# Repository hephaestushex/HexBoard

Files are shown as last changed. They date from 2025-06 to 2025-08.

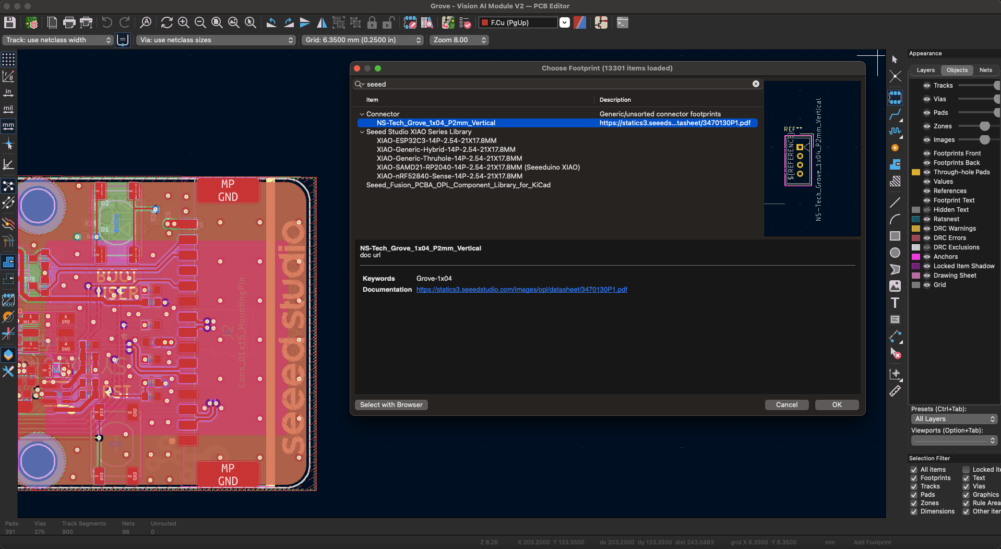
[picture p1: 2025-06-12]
pcb_right/OPL_Kicad_Library-master/images/19.png

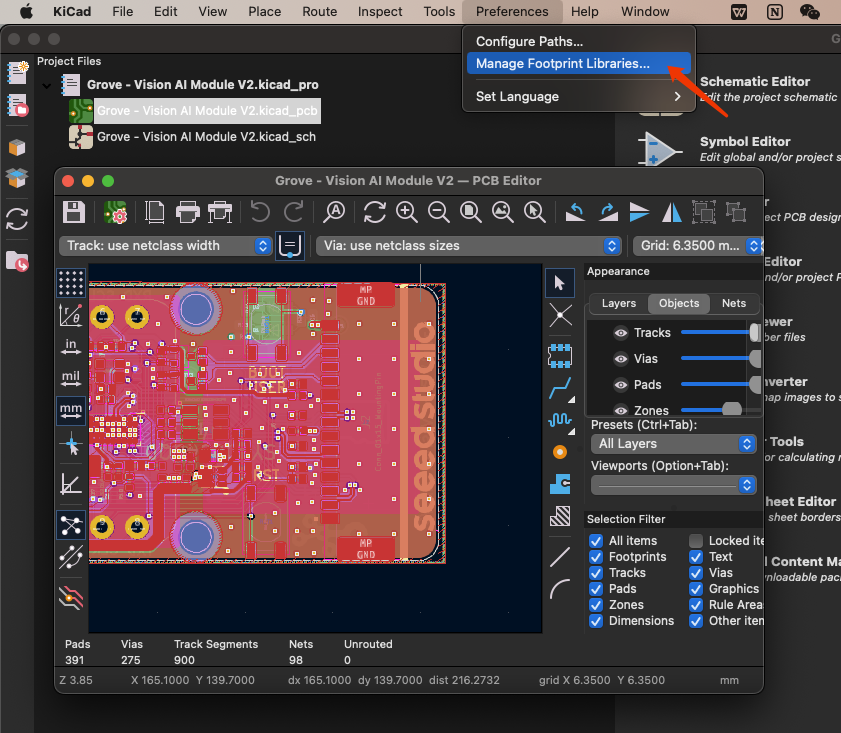
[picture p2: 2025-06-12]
pcb_right/OPL_Kicad_Library-master/images/4.png

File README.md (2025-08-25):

# HexBoard







A wireless split keyboard designed by HephaestusHex. It uses the SEEED Studio XIAO nRF52840 for wireless bluetooth connectivity

I made this split keyboard because it was a great project for learning PCB design, ergonomics, case design, keyboard firmware, and more. I wanted to make a split keyboard specifically because during my research, I found it's better than a regular keyboard because of ergonomics that I won't get into. Ben Vallack has [videos](https://www.youtube.com/@BenVallack) that gets into the details.

# YouTube Demo

Access the youtube demo [here](https://www.youtube.com/watch?v=F45BFvxeQR0)

# CAD
## PCB











## Case



# Firmware

This kb uses ZMK for firmware. Due to ZMK's requirement of using another repo, all of the zmk code is in this [repo](https://github.com/hephaestushex/zmk-config-hexboard)

# BOM

| Name | Reference | Quantity | Value | Footprint | Part Link | Description | Price (USD) |
| --- | --- | --- | --- | --- | --- | --- | --- |
| 1N4148 Diodes | D1-18 | 36 | 1N4148 | D_DO-35_SOD27_P7.62mm_Horizontal | [AliExpress](https://www.aliexpress.us/item/1005004962400215.html) | Used for switch matrix | $1.01 |
| Gateron KS-33 Low Profile Switches | SW1-18 | 36 |  | Gateron-KS33-Solderable-1U | [AliExpress](https://www.aliexpress.us/item/1005006637645158.html) | Low-profile switches | $25.22 |
| Seeed XIAO nRF52840 | U1 | 2 |  | XIAO-nRF52840-DIP-Batt | [AliExpress](https://www.aliexpress.us/item/1005008484816031.html) | Bluetooth MCU for wireless split connectivity | $31.09 |
| 601730 3.7V LiPo Battery | J1 | 2 | 250mAh | PinHeader_1x02_P2.54mm_Vertical | [AliExpress](https://www.aliexpress.us/item/1005006584143607.html) | Battery for MCU | $5.47 |
| PCB | hexboard-left, hexboard-right | 2 |  |  | [JLC PCB](https://jlcpcb.com/) | PCB for the left and right halves of the keyboard | $24.33 |
| M3x5x4 Heatset Inserts |  | 8 |  |  | [AliExpress](https://www.aliexpress.us/item/4000232858343.html) | Heatset inserts for mounting components | $6.23 |
| M3x6 Screws | H1-4 | 8 |  | MountingHole_3.2mm_M3 | [AliExpress](https://www.aliexpress.us/item/32794842281.html) | Screws for securing the PCB to the case | $2.89 |
| Slide SPDT Switches | SW19 | 2 |  | SW_Slide_SPDT_Straight_CK_OS102011MS2Q | [AliExpress](https://www.aliexpress.us/item/1005007162182882.html) | Slide switch for power control | $1.46 |
| Case |  |  |  |  |  | Free since I already have filament | $2.78 |
| Keycaps |  |  |  |  |  | Free since I already have filament | $0.66 |
| AliExpress Total  |  |  |  |  |  |  | $75.80 |
| JLCPCB Total  |  |  |  |  |  |  | $30.80 |
| Grand Total |  |  |  |  |  |  | $113.04 |

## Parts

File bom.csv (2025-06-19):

Name | Reference | Quantity | Value | Footprint | Part Link | Description | Price (USD)
1N4148 Diodes | D1, D2, D3, D4, D5, D6, D7, D8, D9, D10, D11, D12, D13, D14, D15, D16, D17, D18 | 36 | 1N4148 | D_DO-35_SOD27_P7.62mm_Horizontal | https://www.aliexpress.us/item/1005004962400215.html | Used for switch matrix | $1.01
Gateron KS-33 Low Profile Switches | SW1, SW2, SW3, SW4, SW5, SW6, SW7, SW8, SW9, SW10, SW11, SW12, SW13, SW14, SW15, SW16, SW17, SW18 | 36 |  | Gateron-KS33-Solderable-1U | https://www.aliexpress.us/item/1005006637645158.html | Low-profile switches | $25.22
Seeed XIAO nRF52840 | U1 | 2 |  | XIAO-nRF52840-DIP-Batt | https://www.aliexpress.us/item/1005008484816031.html | Bluetooth MCU for wireless split connectivity | $31.09
502030 3.7V LiPo Battery | J1 | 2 | 250mAh | PinHeader_1x02_P2.54mm_Vertical | https://www.aliexpress.us/item/1005006584143607.html | Battery for MCU | $5.47
PCB | hexboard-left, hexboard-right | 2 |  |  | https://jlcpcb.com/ | PCB for the left and right halves of the keyboard | $24.33
M3x5x4 Heatset Inserts |  | 8 |  |  | https://www.aliexpress.us/item/4000232858343.html | Heatset inserts for mounting components | $6.23
M3x6 Screws |  | 8 |  |  | https://www.aliexpress.us/item/32794842281.html | Screws for securing the PCB to the case | $2.89
Slide SPDT Switches | SW19 | 2 |  | SW_Slide_SPDT_Straight_CK_OS102011MS2Q | https://www.aliexpress.us/item/1005007162182882.html | Slide switch for power control | $1.46
Total |  |  |  |  |  |  | $97.7

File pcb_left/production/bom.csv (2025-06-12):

Designator | Footprint | Quantity | Value | LCSC Part #
D1, D10, D11, D12, D13, D14, D15, D16, D17, D18, D2, D3, D4, D5, D6, D7, D8, D9 | D_DO-35_SOD27_P7.62mm_Horizontal | 18 | 1N4148
J1 | PinHeader_1x02_P2.54mm_Vertical | 1 | Conn_01x02_Pin
SW1, SW10, SW11, SW12, SW13, SW14, SW15, SW16, SW17, SW18, SW2, SW3, SW4, SW5, SW6, SW7, SW8, SW9 | Gateron-KS33-Solderable-1U | 18 | SW_Push_45deg
SW19 | SW_Slide_SPDT_Straight_CK_OS102011MS2Q | 1 | SW_SPDT
U2 | XIAO-nRF52840-DIP-Batt | 1 | XIAO-nRF52840-SMD

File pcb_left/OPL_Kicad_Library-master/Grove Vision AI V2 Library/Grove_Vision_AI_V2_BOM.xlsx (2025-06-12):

Layer Jump | Number | Name | Specification | Operating Temperature | MPN Code | Quantity | Base | Plug Position | Process
N | 301010000 | SMD RES 0R-5%-1/16W;0402 |  | -55°C to 155°C | RC0402JR-070RL | 3 | 1 | R29,R30,R39 | SMT1
N | 301010004 | SMD RES 10K-5%-1/16W;0402 |  | -55°C to 155°C | RC0402JR-0710KL | 7 | 1 | R5,R7,R8,R23,R24,R31,R38 | SMT1
N | 301010008 | SMD RES 510K-5%-1/16W;0402 |  | -55°C to 155°C | RC0402JR-07510KL | 1 | 1 | R35 | SMT1
N | 301010456 | SMD RES 100K-1%-1/16W;0402 |  | -55°C to 155°C | RC0402FR-07100KL | 7 | 1 | R6,R10,R11,R16,R32,R33,R37 | SMT1
N | 301010495 | SMD RES;5.1K-1%-1/16W;0402 |  | -55°C to 155°C | RC0402FR-075K1L | 3 | 1 | R2,R3,R36 | SMT1
N | 301010746 | SMD RES 2.2K-1%-1/16W;0402 |  | -55°C to 155°C | RC0402FR-072K2L | 10 | 1 | R1,R4,R13,R14,R15,R19,R20,R21,R22,R40 | SMT1
N | 301011331 | SMD RES 22.1K-1%-1/16W;0402 |  | -55°C to 155°C | RC0402FR-0722K1L | 2 | 1 | R26,R34 | SMT1
N | 302010004 | SMD CAP Ceramic 100nF-16V-10%-X7R;0402 |  | -55°C to 125°C | CC0402KRX7R7BB104 | 18 | 1 | C5,C8,C13,C20,C21,C22,C23,C24,C25,C26,C27,C29,C30,C31,C32,C35,C36,C39 | SMT1
N | 302010006 | SMD CAP Ceramic 10nF-50V-10%-X7R;0402 |  | -55°C to 125°C | CC0402KRX7R9BB103 | 1 | 1 | C3 | SMT1
N | 302010049 | SMD CAP Ceramic 12pF-50V-5%-NPO;0402 |  | -55°C to 125°C | CC0402JRNPO9BN120 | 2 | 1 | C14,C15 | SMT1
N | 302010051 | SMD CAP Ceramic 220nF-16V-10%-X7R;0402 |  | -55°C to 125°C | CC0402KRX7R7BB224 | 1 | 1 | C16 | SMT1
N | 302010407 | SMD CAP Ceramic 4.7uF-10V-10%-X5R;0402 |  | -55°C to 85°C | CC0402KRX5R6BB475 | 7 | 1 | C4,C6,C7,C9,C10,C28,C34 | SMT1
N | 302010519 | SMD CAP Ceramic 10uF-10V-20%-X5R;0402 |  | -55°C to 85°C | CC0402MRX5R6BB106 | 2 | 1 | C11,C37 | SMT1
N | 302013249 | SMD CAP Ceramic 1uF-10V-10%-X5R;0402 |  | -55°C to 85°C | CL05A105KP5NNNC | 5 | 1 | C1,C2,C17,C18,C19 | SMT1
N | 303010544 | SMD Inductor 4.7uH-20%-1.1A;0806 |  | -40°C to 105°C | VLS201610HBX-4R7M-1 | 1 | 1 | L1 | SMT1
N | 303011858 | SMD Inductor 470nH-20%-2.6A;0603 |  | -40°C to 125°C | TFM160808ALC-R47MTAA | 2 | 1 | L2,L3 | SMT1
N | 304011053 | SMD Diode Schottky 40V-1A;SOD-323 |  |  | B5819WS SL | 4 | 1 | D1,D2,D3,D4 | SMT1
N | 304090121 | SMD LED Clear-Green;0402 | As posted |  | BL-HGE37A-AV-TRB | 1 | 1 | LED2 | SMT1
N | 304090746 | SMD LED Clear-Yellow;0402 | As posted |  | 16-213/Y2C-AN2Q1B/3T | 1 | 1 | LED1 | SMT1
N | 305030071 | SMD MOSFET N-CH 20V-500mA;SOT-523 |  |  | CJ1012 | 5 | 1 | Q1,Q2,Q3,Q4,Q5 | SMT1
N | 306011444 | SMD Crystal;24MHz-12pF-10ppm-4P-2.0*1.6*0.5mm |  | -40°C to 85°C | Y2400FE001 | 1 | 1 | X1 | SMT1
N | 310011697 | SMD IC MCU;Dual Cortex-M55 Core(Max 400MHz)-With a 400MHz NPU;WLCSP-65 | L5.58*W2.27mm | -40°C to 85°C | HX6538-A01TWA | 1 | 1 | U1 | SMT1
N | 310032794 | SMD IC PMIC;DCDC Buck-ADJ-2.2MHz-4A;DFN1.5×1.5-6 |  | -40°C to 85°C | SY80004DQD | 2 | 1 | U4,U6 | SMT1
N | 310032813 | SMD IC PMIC;LDO-1.8V-300mA;XTDFN-1*1-4L |  | -40°C to 125°C | SGM2036S-1.8XXDH4G/TR | 1 | 1 | U3 | SMT1
N | 310071431 | SMD IC Interface USB to High Speed TTL;QFN16 | USB to High-Speed Serial Port | -40°C to 85°C | CH343P | 1 | 1 | U2 | SMT1
N | 310091468 | SMD IC Memory;128Mbit-1.8V;SOIC-8 |  | -40°C to 85°C | W25Q128JWSIQ | 1 | 1 | U5 | SMT1
N | 311020009 | SMD Top Button 4N;4P-L4.6*W3.2*H2.5mm |  | -20°C to 70°C | SKRPADE010 | 1 | 1 | RST1 | SMT1
N | 311020518 | SMD Top Button 1.57N;4P-L4.6*W3.2*H2.5mm |  | -30°C to 85°C | SKRPABE010 | 1 | 1 | BOOT1 | SMT1
N | 312030502 | SMD DIGITAL MIC OMNI -26dBFS;OCLGA-4:3.5*2.65*0.94mm |  | -40˚C to 100˚C | MSM261D3526H1CPM | 1 | 1 | MIC1 | SMT1
N | 319015667 | PCB;Grove - Vision AI Module V2 -蓝油白字-4层 | 20*40*1.6mm-ENIG-FR4;Steel mesh code；404012305 |  |  | 1 | 1 |  | SMT1
N | 320011358 | SMD USB TYPE C-W/P;12+4P-8.94*7.35*3.26mm |  | -30°C to 85°C | USB-31C-F-16P-L7.35 | 1 | 1 | J1 | SMT1
N | 320031231 | DIP Black Female Header VERT;1*7P-2.54-5.0mm |  | -40℃ to 105℃ |  | 2 | 1 | P8,P9 | Unit
N | 320060904 | SMD FPC CONN Bottom Contact;15P-1.0mm;L19.9*W6.76*H2.0mm |  | -30°C to 85°C | ST-FPC-W102015-D | 1 | 1 | J2 | SMT1
N | 320090535 | SMD uSD Card Holder;9+4P-L11.25*W6.96*H1.42mm |  | -25°C to 70°C | ST-TF-MR267 | 1 | 1 | J5 | SMT1
N | 320110032 | SMD Grove Female Header-Beige;4P-2.0-90D | 2.0-4PHorizontal Mount with Locking Socket |  | PHS-4A horizontal mount | 1 | 1 | J3 | SMT1

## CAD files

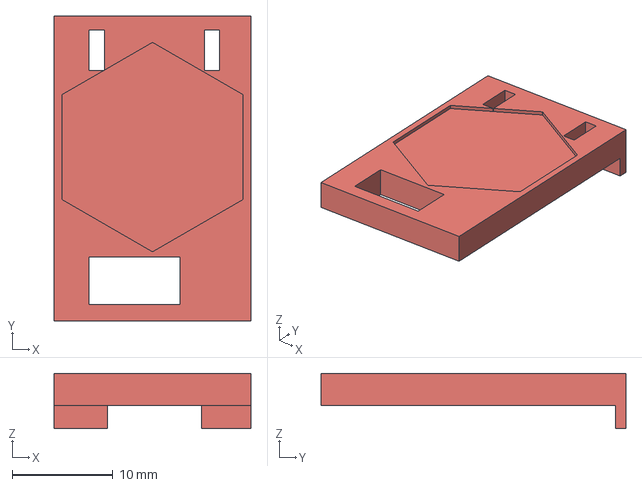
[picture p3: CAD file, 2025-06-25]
cad/Right Cover.step
19.5 x 30.3 x 5.50 mm

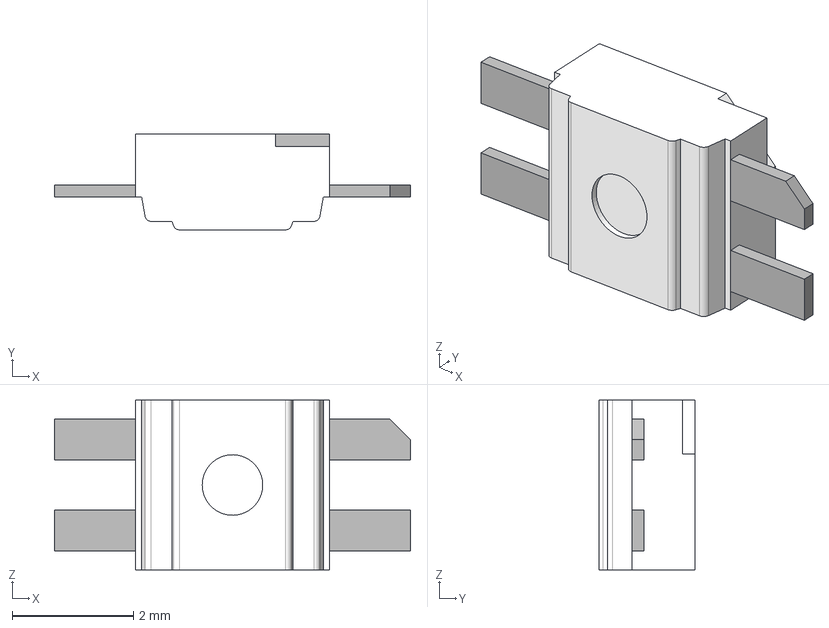
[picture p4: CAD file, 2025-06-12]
pcb_left/cheyao macropad main PCB-third_party_neopixel.petty/SK6812MINI-E.step
5.88 x 1.58 x 2.80 mm

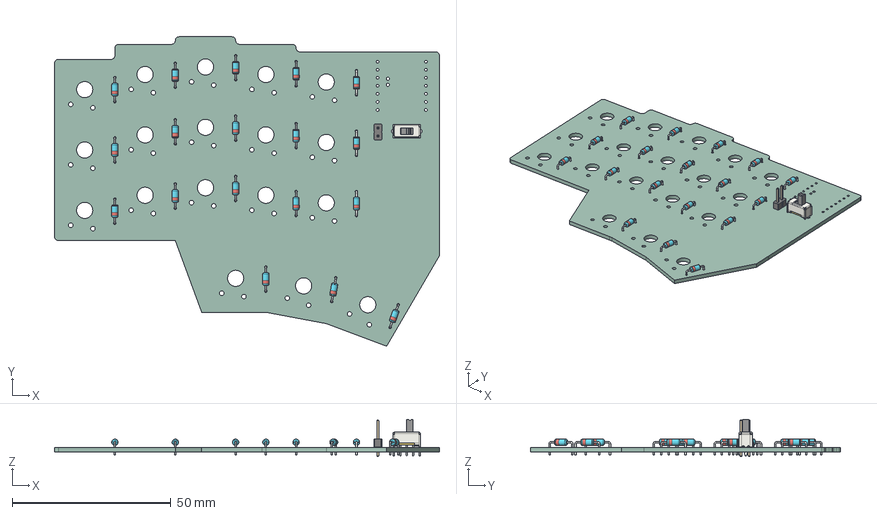
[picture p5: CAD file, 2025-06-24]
pcb_left/hexboard_left.step
121.4 x 97.6 x 11.7 mm
D_DO-35_SOD27_P7.62mm_Horizontal x 18
PinHeader_1x02_P2.54mm_Vertical
SW_Slide_SPDT_Straight_CK_OS102011MS2Q
hexboard_PCB

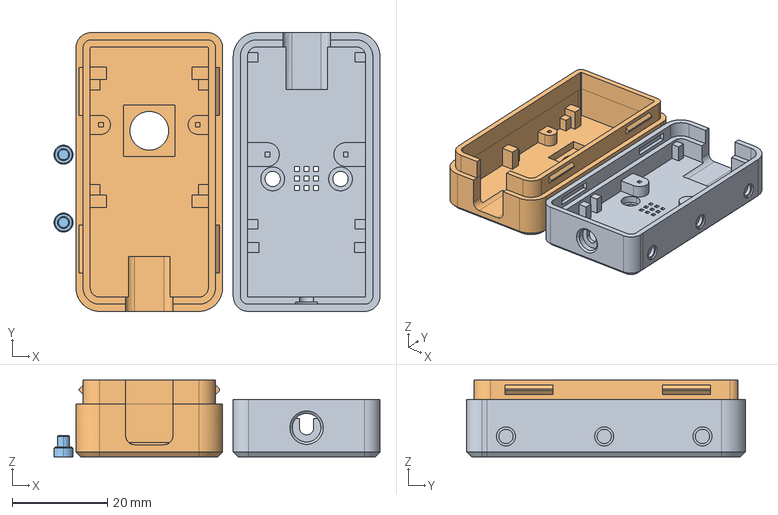
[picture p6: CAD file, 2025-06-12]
pcb_left/OPL_Kicad_Library-master/Grove Vision AI V2 Library/himax.stp
68.4 x 58.5 x 16.1 mm

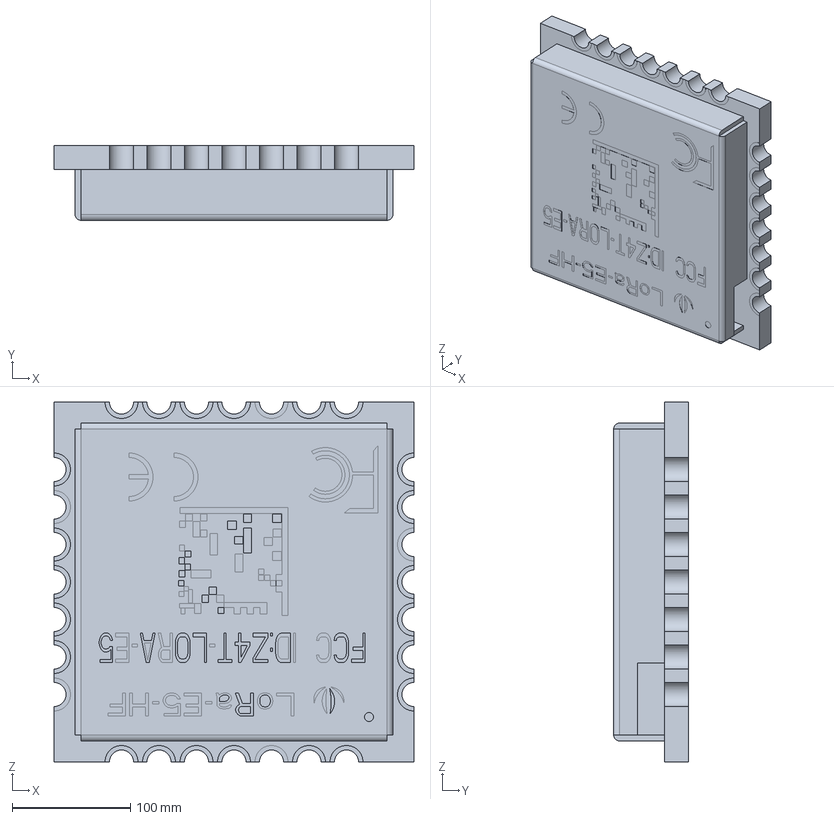
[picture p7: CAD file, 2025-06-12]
pcb_left/OPL_Kicad_Library-master/Seeed Studio Wio Series/Wio-E5-LE/LoRa-E5-LE-HF_3D_File.stp
304.8 x 63.8 x 304.8 mm

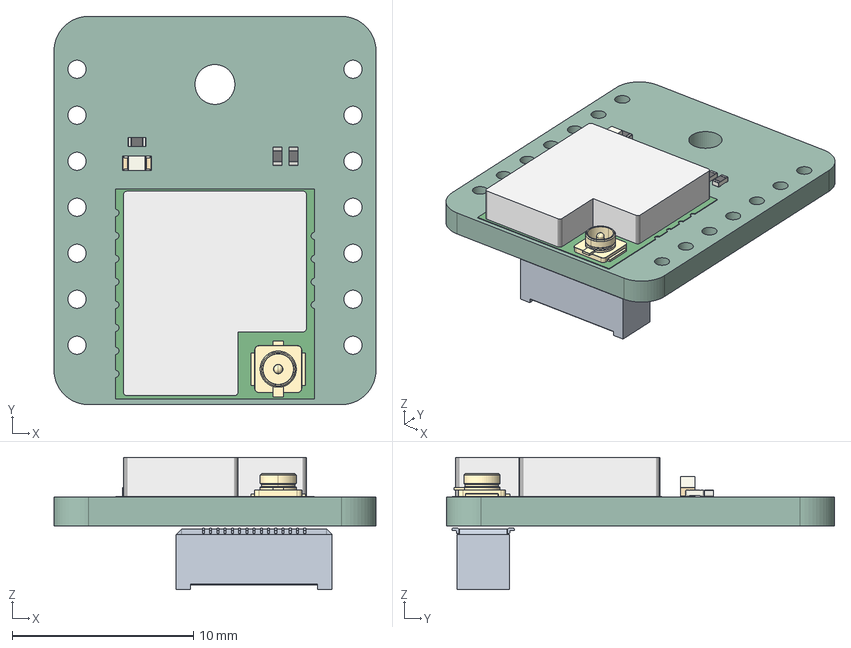
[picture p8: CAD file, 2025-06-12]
pcb_left/OPL_Kicad_Library-master/Seeed Studio Wio Series/Wio-SX1262/Wio-SX1262_for_XIAO_3D_file.step
17.8 x 21.4 x 7.30 mm
R_0402_1005Metric x 3
LED_0603_1608Metric
PCB
BF04-30pin-35H
Wio-SX1262 for XIAO V1.0_PCB

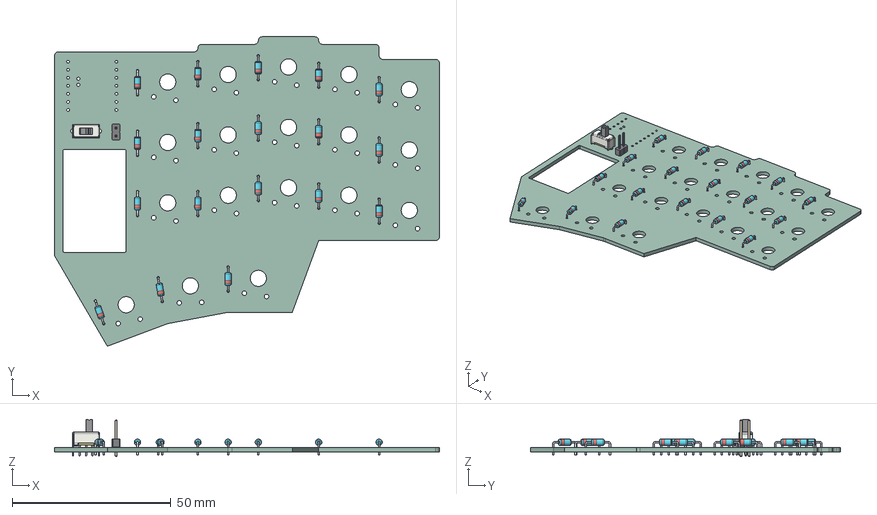
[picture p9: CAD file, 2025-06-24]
pcb_right/hexboard_right.step
121.4 x 97.6 x 11.7 mm
D_DO-35_SOD27_P7.62mm_Horizontal x 18
PinHeader_1x02_P2.54mm_Vertical
SW_Slide_SPDT_Straight_CK_OS102011MS2Q
hexboard_PCB

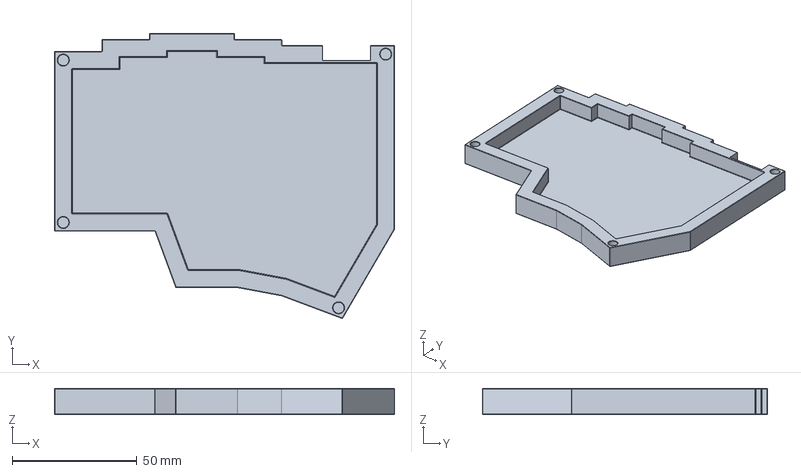
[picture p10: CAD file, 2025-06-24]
production/case/Left Shell.step
136.5 x 114.4 x 10.5 mm

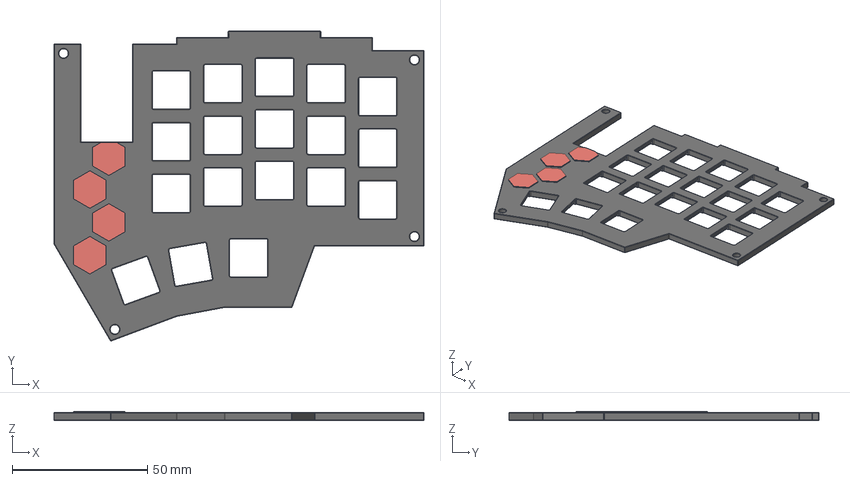
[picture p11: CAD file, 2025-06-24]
production/case/Right Plate.step
136.5 x 114.4 x 3.40 mm

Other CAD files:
cad/Left Cover.step
production/case/Right Shell.step
cad/Left Plate.3mf
cad/Left Plate.step
cad/Right Plate.3mf
cad/Right Shell.step
pcb_left/OPL_Kicad_Library-master/Grove Vision AI V2 Library/himax.3mf
pcb_right/OPL_Kicad_Library-master/Grove Vision AI V2 Library/himax.3mf
production/case/Left Plate.3mf
production/case/Left Plate.step
production/case/Right Plate.3mf

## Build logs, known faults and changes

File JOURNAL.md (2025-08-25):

---
title: "HexBoard"
author: "hephaestushex"
description: "A wireless split keyboard powered by the nRF52840"
created_at: "2025-06-05"
---

# Total Time Spent: 33.5 Hours (including building)

# June 9th: Got some initial planning done

## Keyboard Layout

I started off by creating a keyboard layout.
Some tinkering later, this is what it looks like in Keyboard Layout Editor



It's only one half, with no column stagger (I haven't measured my hands yet) but it would come out to a 36-key layout



As for the keymap, I liked this one by Rico Sta. Cruz. I'll probably use QWERTY, but I like the way they navigate between layers

## Microcontroller

I initially wanted to make this keyboard wireless, considering the state of my desk

WIN_20250609_16_52_57_Pro
my desk rn... not looking good

Unfortunately, after a post on slack and some research, this isn't feasible. I could use an aliexpress clone, but apparently it's not reliable

Anyway, by this point I decided that a pi pico would be better. Ideally, usb-c, as the microUSB connectors tend to break off.

I started by looking at the Seeed Studio XIAO RP2040 board. With the split connectivity (TX/RX) pins, there is 9 more pins, which would work out for my layout.

It's tight, but it might just work.

But hold on... I found a Seeed Studio XIAO nRF52840 Board, and it is similar to the nice!nano, but so much more cheaper. The only caveat is that the battery pins are exposed by pads. A google search yielded the ergonaut one, which solves this problem by using holes and filling them with solder.


location of the battery pins


solution used in the ergonaut one

## Keyswitches

I want this keyboard to be low-profile, so I went looking for some low profile keyswitches. I ended up finding the gateron ks-33 low profile switches, which looks good.

## Miscellaneous Parts

I'll use THT diodes for the matrix, probably 1N4148 diodes.

**Total time spent: 3h**

# June 10th: PCB Design

With all the hardware choices out of the way, I started designing the schematic and PCB.

I downloaded some libraries and setup the key switch matrix



my switch matrix.

I plan on making this a reversible matrix, so its only one half.

I then decided to do per key RGB, so I setup that too.



Its much simpler.

From there I wired up the microcontoller and battery



With that out of the way, I started on the PCB, which was relatively easy.



This is the location I settled on.

**Total time spent: 3h**

# June 11th: PCB Routing

I used @cheyao's reversible sk6812 mini LED footprint, and positioned those and the leds.

I then wired all of them up.



I don't like the wiring towards the MCU, so I'll probably fix it tomorrow.

I couldn't decide on the mcu footprint, so I'm still working on it.
For now I'm using this footprint used in the ergonaut one


Also it appears that a reversible footprint does not exist for the ks-33 so looks like I'm making two halves.

After all of that, this is the final pcb for today.



**Total time spent: 1.5h**

# June 12th: Rerouting + New PCB Footprint

I started off by realizing I probably can't SMD solder, so I created this footprint, using the XIAO nRF52840 DIP as a base and added the pads from the ergonaut one footprint.



The holes are so that I can use the soldering method used in the ergonaut one.

From, there I positioned the switch and battery connector.



The battery connector is simply two holes for two wires.

I then placed some mounting holes, two in the left half and one on the right half,
and finally one in the thumb cluster



Finally, the board outline and its time to reroute, this time beautifully.

I had to shuffle around some parts, replace a few footprints. I also decided to nix the leds, because a, I have no idea how to smd solder, and b, soldering 144 smd pins is too much.

This is the result







I exported that, then flipped it over and rerouted





the cost comes out to $8.50 per pcb.

To check if I'm still under the limit, I decided to put together the BOM.



I sourced everything from aliexpress except the pcb and case (not on yet since I have no idea how much filament it needs)

I also made the BOM in table format in the README.md

**Total time spent: 4h**

# June 13th: Case Design and PCB Redesign

I started to design the case, when I realized that my ergonomic setup wouldn't work with Keyboard Layout editor, as apparently it can't handle eighth units.
So I'm stuck designing my own plate. 

When I hopped into kicad, I realized that my thumb cluster was not properly designed, so I basically redid the pcb, this time capturing the measurements necessary. This also helped me reduce the number of vias I used, making it cheaper!

## Right Half



## Left Half



I also redid the cost calculations with the new pcbs, but it didnt change.

Now, I can start with the case/plate.

Since Keyboard layout editor doesn't support eight units, I have to design my own plate, which kinda sucks.

Anyway, I tried my best to create my own plate, and this is what I go before I gave up.



This was my first time using fusion, so it took forever, dealing with constraints, rectangular patterns and so much more.

**Total time spent: 5h**

# June 15th: Case Redesign

This clearly wasn't working, so I tried KLE again. I just ignored the warnings, and came up with this plate.



its so much better, and I can properly deal with this. Obviously the plate isn't meant to be a square, so thats a tomorrow problem

**Total time spent: 30min**

# June 16th: Case Design (for real this time)

I decided to start designing the case, and it looked good!

45 mins in and this is what I have



It looks good, so I designed a cross section to see how it would mount



its way too large (2 cm), so I realized i should probably use m2 bolts instead.

Back to PCB design ... sigh

It wasn't too bad, I just made two different folders for each half. 

Here's the new folder structure



A quick edit in the footprint assignment tool yielded a fixed pcb.

.

**Total Time spent: 1h**

# June 17th: Case Done*

I started off with some research as to the dimensions of my case. It was very boring, but eventually 
I found out that the distance between the bottom of the plate and the top of the case floor should be 4.5mm

The research led me to find out that my current hardware is good, so I just went with the m3 bolts. The heads will protrude now, but that should be fine.

The fact that the heads will protrude made me have to move the bolts to the side, which ended up looking like a sandwich mount, like this, except for the fact that the bolts will come from the top instead



Heres what the bottom looks like, after redoing the pcbs, schematics, and the sketch



As for the top, it was as simple as copying over the outline and fixing the holes in place.



The plate should be 3mm thick, with 1.2mm thick rectangles for the switch to clip onto. I didn't design these yet, as I want to do it after receiving the switches, which would allow me to experiment with mounting styles.

heres how the plate looks after a quick extrusion





i still need to fillet it tho

**Total time spent: 3h**

# June 18th: Case Fully Done

I started off by redoing the extrusions, so I can create a divot.

It was time consuming, but 30 mins later I got this 



You can see the parts where the switch clips to.

I also took some time to fillet the entire case.

Filleted the top plate:



And the bottom case:



That's pretty much it for the case so I exported, both left and right.

I put the cad files in the repo, and that's all I did for today.



**Total time spent: 1h**

# Jun 19th: Firmware Done*

Since I'm using the nRF52840, my only options for firmware are ZMK and KMK. The docs for KMK say that it has to be precompiled, and a whole bunch of nonsense that made it not worth it to use KMK. ZMK isn't any easier, but at least there's a lot of documentation for it.

I started off with Joe Scotto's tutorial, but it looked out of date, plus mine is split. So, time to delve into the docs.

It took a while to find what I needed, since the actual development of shields was put in the later sections of the docs. I pretty much installed zmk, created a new repo for it, and started creating!

## Some screenshots of the code required









The last image is of my keymap. For now, its pretty sparse, but I plan on filling it out fully.

an hour in, its time for building!

I sure hope that no bugs will come!

**There. were. so. many. bugs.**

The terrible part is that it takes forever for these bugs to show up, since it takes time to build.



The first two were the initial builds, but the last three are bugs in my code.

If you noticed in my keymap, I actually used a Colemak layout. I wanted to learn colemak, so I'm taking this as an opportunity to learn it.

so while it takes time to build ...



im learning colemak!



Finally at 1:23 it built.



FINALLY!!!!

Here's my colemak accuracy by the way:



That's pretty much everything I think I have to do before I submit.

I pushed the two uf2 files to github



I took some time to revise the README and the BOM.

AliExpress for some reason changed the prices on me, so I have to update the prices. It also allowed me to fix items that ship later.

That looked to be pretty much everything, so I checked the website to see if I'm missing anything.

I was missing a couple of images, plus some BOM formatting. It took a while to place all the switches, so in total, about 45 mins.



This is how it looked once I placed all of them. 

That's it, so I'm going to submit this.

**Total time spent: 3.5h**

# June 23rd: Case Redesign

I already submitted this in the slack, but I realized my case didn't have much design to it. I wanted to create a design to boost my chances of getting accepted, plus, i didn't like the look of a plain pcb.

1h 30mins in, I got this:



I took some time to design around the xiao, but I liked this look in the end.

I meant to also add some color, so I re did the appearances close to what it would look like IRL



After doing that, I realized I didnt like the look of the xiao board, so I added some material to hide that aswell.

It allowed me to completely hide the usb-c port 



And this is the final design!



I have black and red pla filament, and this is what itll probably look like.

I also decided to take a render, and I added this to the README



From there I refactored the object and exported everything. I also took the time to colorize the case in the Bambu Slicer, and saved it as a 3mf file.



the colorized part is above all the black parts, so there is only one filament change.

Now, the assembly steps looks like solder diodes, switches, mcu, battery onto pcb, insert switches into plate, solder switches to PCB, screw plate to bottom shell. 

**Total time spent: 3h**

# July 10th: Assembly (Part One):

Note: I forgot to journal this, so this is written on july 23rd, when I finally got the batteries.

I received all the parts except for the battery, so I printed off the plate to start assembly.



as you can see, the plate and pcb are touching, meaning I cant use diodes

Unfortunately, the plate ended up being too thick, and the diodes wont fit. (it would have worked if it was SMD).

So I had to reprint thinner plates. After they printed I started snapping in the switches.




As you can see in the back, I also placed the diodes in the holes.

After this, I realized I had made another mistake. This time I foolishly assumed in my cad that I would SMD solder the XIAO. I had soldered on the headers, so now I had to remove them.



The process was pretty simple, with using diagonal cutters to cut the black parts, remove them, and then use the soldering iron plus some tweezers to remove each pin.

I then soldered the diodes + the mcu, cut the legs off, and soldered the switches as well.




Here's how it looked.

It was undercity tomorrow, so I basically speedran everything. I had forgotten to print the bottom part, so I put it to print and fell asleep. 

**Total time spent: 4h**

# July 11th: Assembly (Part Two)

I woke up (at like 4AM), put the heatset inserts in, and finally assembeled the keyboard.




I slapped the basic firmware in, and left for undercity. In Github HQ I realized that certain keys didn't work, so I had to fix it later.

**Total time spent: 30mins**

# July 22nd: Assembly (Part Three):

I received the batteries (finally!), and realized the keyboard still doesn't work. What I did was find the keys that didn't work, replaced them with a letter (T) and tried again. Looks like middle key on the thumb cluster on the left half doesn't work, and the entire thumb cluster on the right half doesn't work. I also figured out that bridging the pins on the left half worked, but not on the right. Looks like I fried a pin. I'll have to fix that. I had to leave, so that's all I did.

**Total time spent: 30mins**

# July 25th: Done! (sorta):

I wrote the title with the Hexboard, but since my current WPM is so slow, I switched back to my regular keyboard.

Part one: Battery

I tried getting the battery working, but for some reason I never got it working on the left half. I updated the firmware, resoldered the joints, but it still doesnt work. It works on the right half though. 
I added some code to the .overlay file in the zmk, and it supposedly reports the battery level. currently this doesn't matter, as zmk only reports the left half's battery, and only the right half is wireless. (the left half is only connected for power. Overall, this isn't too bad, as its only one usb-c wire on my desk. 

Part two: missed keys.

The only key on the left half that didn't work was the modifier, but upon further inspection it appeared that I forgot to solder a diode. As for the right half, it was more complicated. I rebuilt the firmware, using another pin, and soldered a wire from that pin (pin 7) to that row. I still had one problem though. The reset button on the right half was broken, and I had to find a workaround. I ended up grabbing some tin foil and touching that to the contacts. Only one key worked, so I inspected the board even more. It appeared that I burned the contacts on the PCB, so the traces never connected to the switch. I ended up soldering a wire to replace the traces that the switch couldnt connect to. 

WIN_20250726_16_46_26_Pro

WIN_20250726_16_46_30_Pro

WIN_20250726_16_47_52_Pro

With that, I was finished. I just had two more things that I wanted to fix/add. One was fixing the battery on the left half, but that means I would have to desolder the entire mcu and try to clean the joints up. There was also a chance that the battery board was simply fried, and I don't want to go through all that. The second one was adding ZMK studio support to my keyboard. This means that I can easily modify the keymap, without building new firmware.

It turns out that this process takes a while, as I have to define a physical layout. In the end, i got it in a web tool



and the ide



So I pushed it to Github and let it build, while I got some more tin foil.

After I reflashed the mcus, it worked!



So that's it! It's finished! 

I'll record some footage and upload it to youtube for a demo.

**Total time spent: 3h**

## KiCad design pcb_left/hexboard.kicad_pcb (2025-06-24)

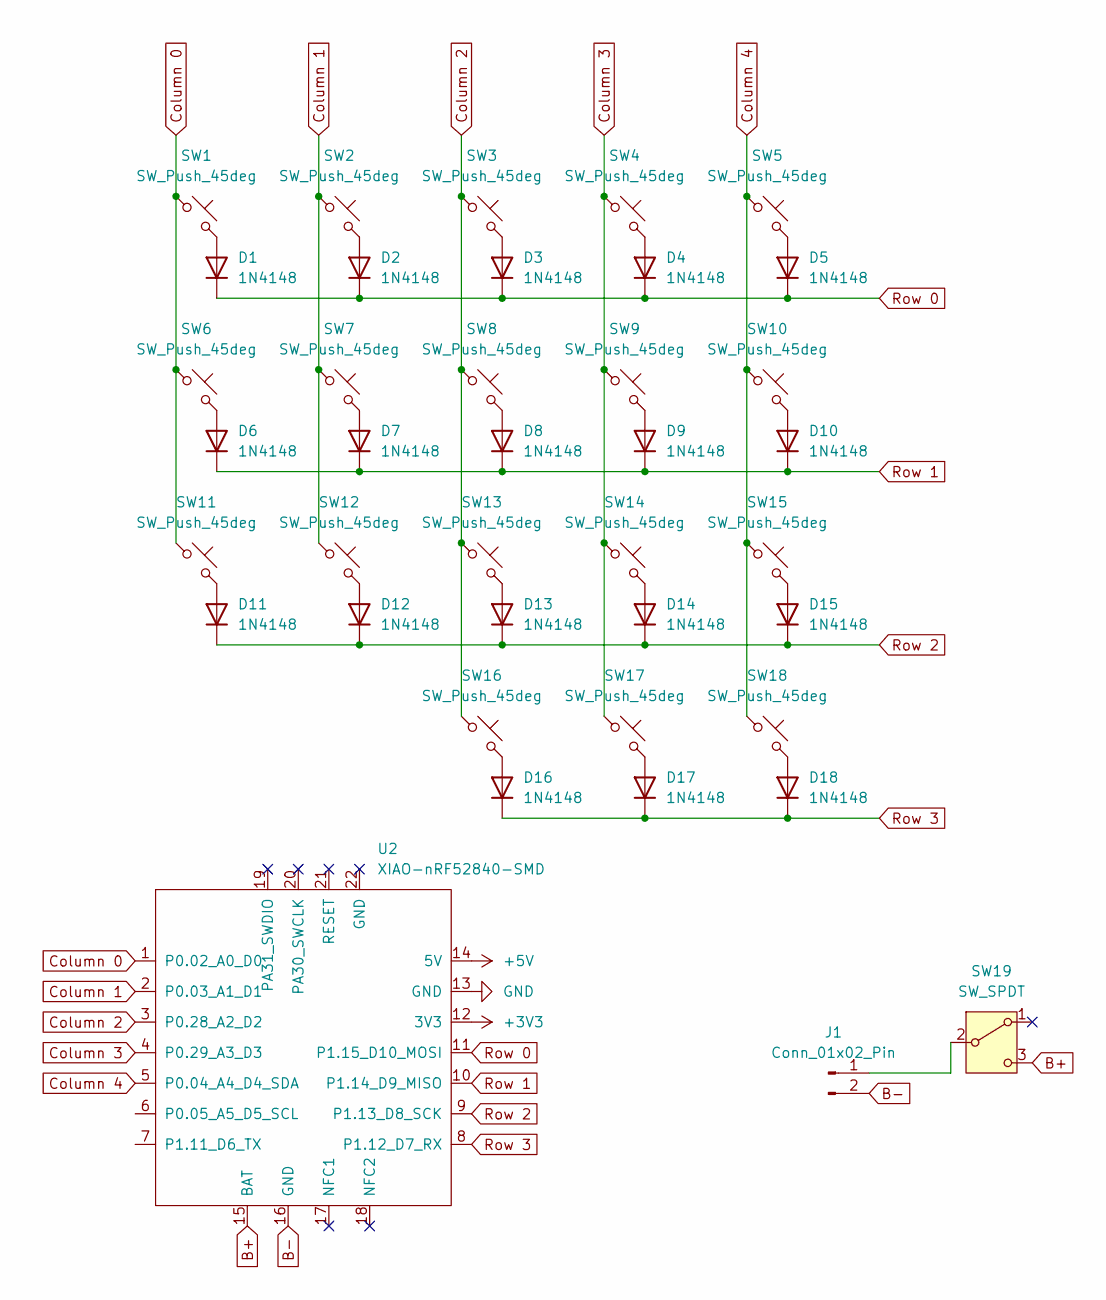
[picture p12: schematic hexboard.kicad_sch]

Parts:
D1, D2, D3, D4, D5, D6, D7, D8, D9, D10, D11, D12, D13, D14, D15, D16, D17, D18: 1N4148; D_DO-35_SOD27_P7.62mm_Horizontal
J1: Conn_01x02_Pin; PinHeader_1x02_P2.54mm_Vertical
SW1, SW2, SW3, SW4, SW5, SW6, SW7, SW8, SW9, SW10, SW11, SW12, SW13, SW14, SW15, SW16, SW17, SW18: SW_Push_45deg; Gateron-KS33-Solderable-1U
SW19: SW_SPDT; SW_Slide_SPDT_Straight_CK_OS102011MS2Q
U2: XIAO-nRF52840-SMD; XIAO-nRF52840-DIP-Batt

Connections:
+3V3: U2.12 (3V3)
+5V: U2.14 (5V)
B+: SW19.3 (C), U2.15 (BAT)
B-: J1.2, U2.16 (GND)
Column 0: SW1.1, SW6.1, SW11.1, U2.1 (P0.02_A0_D0)
Column 1: SW2.1, SW7.1, SW12.1, U2.2 (P0.03_A1_D1)
Column 2: SW3.1, SW8.1, SW13.1, SW16.1, U2.3 (P0.28_A2_D2)
Column 3: SW4.1, SW9.1, SW14.1, SW17.1, U2.4 (P0.29_A3_D3)
Column 4: SW5.1, SW10.1, SW15.1, SW18.1, U2.5 (P0.04_A4_D4_SDA)
GND: U2.13 (GND)
unnamed: D1.2 (A), SW1.2
unnamed: D2.2 (A), SW2.2
unnamed: D3.2 (A), SW3.2
unnamed: D4.2 (A), SW4.2
unnamed: D5.2 (A), SW5.2
unnamed: D6.2 (A), SW6.2
unnamed: D7.2 (A), SW7.2
unnamed: D8.2 (A), SW8.2
unnamed: D9.2 (A), SW9.2
unnamed: D10.2 (A), SW10.2
unnamed: D11.2 (A), SW11.2
unnamed: D12.2 (A), SW12.2
unnamed: D13.2 (A), SW13.2
unnamed: D14.2 (A), SW14.2
unnamed: D15.2 (A), SW15.2
unnamed: D16.2 (A), SW16.2
unnamed: D17.2 (A), SW17.2
unnamed: D18.2 (A), SW18.2
unnamed: J1.1, SW19.2 (B)
Row 0: D1.1 (K), D2.1 (K), D3.1 (K), D4.1 (K), D5.1 (K), U2.11 (P1.15_D10_MOSI)
Row 1: D6.1 (K), D7.1 (K), D8.1 (K), D9.1 (K), D10.1 (K), U2.10 (P1.14_D9_MISO)
Row 2: D11.1 (K), D12.1 (K), D13.1 (K), D14.1 (K), D15.1 (K), U2.9 (P1.13_D8_SCK)
Row 3: D16.1 (K), D17.1 (K), D18.1 (K), U2.8 (P1.12_D7_RX)

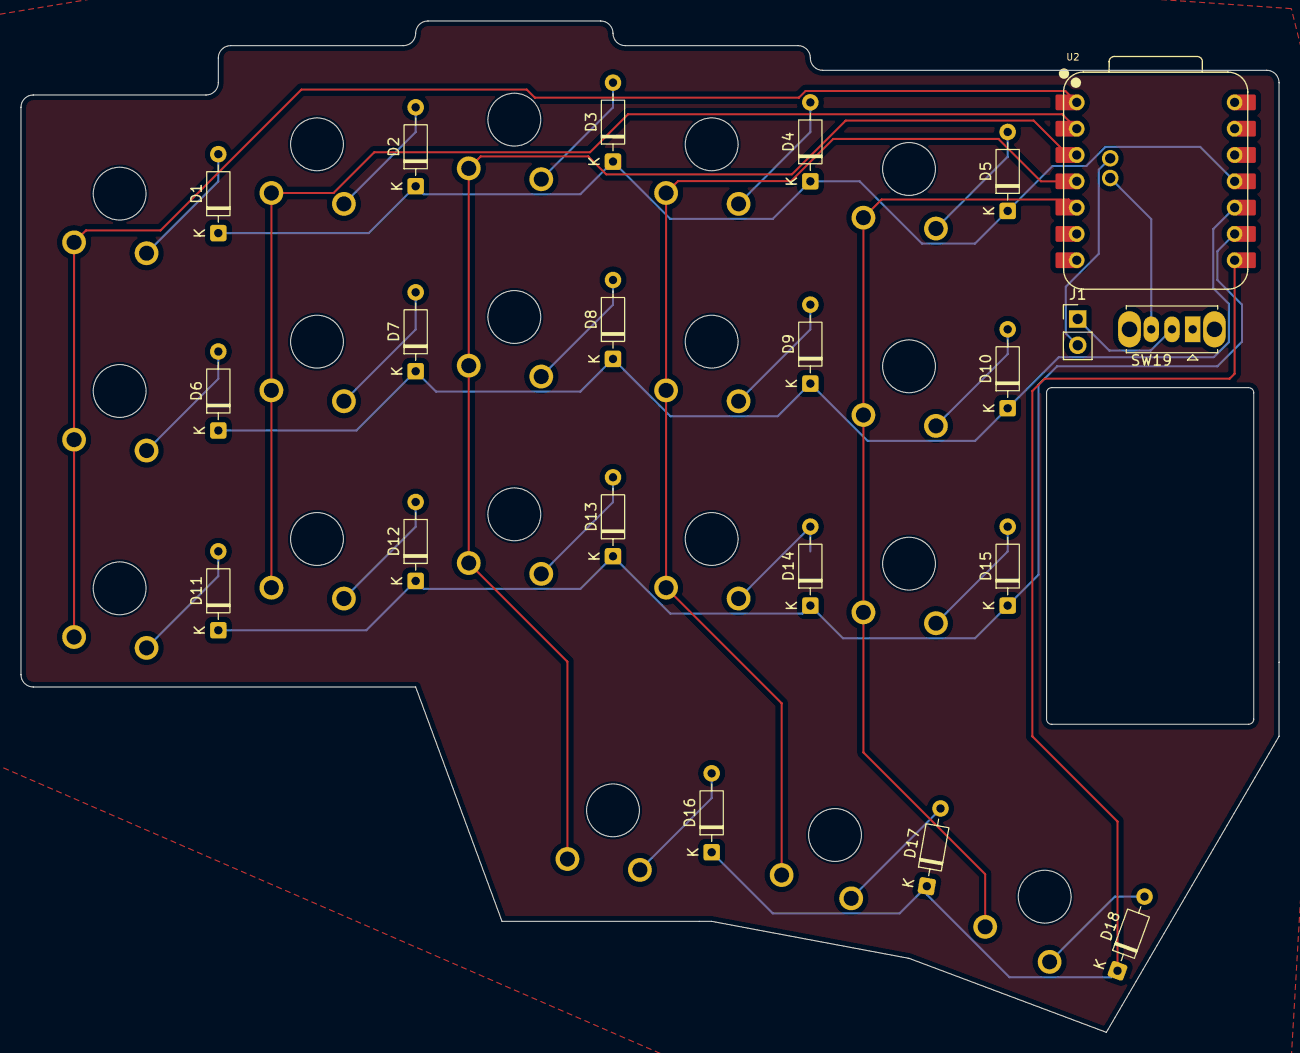
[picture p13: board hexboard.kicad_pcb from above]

Board: 2 copper layers, 121.4 x 97.6 mm, 39 parts (0 on the bottom side), 30 nets.

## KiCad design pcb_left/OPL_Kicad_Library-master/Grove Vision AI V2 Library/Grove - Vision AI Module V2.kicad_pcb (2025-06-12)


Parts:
BOOT1: SW_Push; SW_Push_1P1T_NO_Vertical_Wuerth_434133025816
C1, C2, C17, C18, C19: 1uF; C0402
C3: 10nF; C0402
C4, C6, C7, C9, C10, C28, C34: 4.7uF; C0402
C5, C8, C13, C20, C21, C22, C23, C24, C25, C26, C27, C29, C30, C31, C32, C35, C36, C39: 100nF; C0402
C11, C37: 10uF; C0402
C14, C15: 12pF; C0402
C16: 220nF; C0402
D1, D2, D3, D4: B5819WS; D0805_SOD323
D5, D6, D7, D8: DNP; R0402; MPN DF2S6.8FS
J1: USB_C_Receptacle_USB2.0; USB2.0-TYPE-C
J2: Conn_01x15_MountingPin; FPC_DNC_15P_1.0mm
J3: Conn_01x04_MountingPin; 4P-SMD-2.0mm-RIGHT
J5: ST-TF-MR267; SD-TF-MR267; MPN SD-TF-MR267
L1: VLS201610HBX-4R7M-1; L0806
L2, L3: 470nH; L0603
LED1: Yellow; LED0402
LED2: Green; LED0402
M1: XIAO Connector/DNP; XIAO_Socket
MIC1: MSM261D3526H1CPM; MIC6P-3.5X2.65X0.94MM
Q1, Q2, Q3, Q4, Q5: CJ1012; SOT523
R1, R4, R13, R14, R15, R19, R20, R21, R22, R40: 2.2k; R0402
R2, R3, R36: 5.1k; R0402
R5, R7, R23, R24: 10k; R0402
R6, R16, R32, R33: 100K; R0402; Power Rating 1%; MPN RC0402JR-074K7L
R8, R31, R38: 10K; R0402; Power Rating 5%; MPN RC0402JR-074K7L
R9, R12, R17, R18, R25, R27, R28: DNP; R0402
R10, R11, R37: 100k; R0402
R26, R34: 22K; R0402; Power Rating 1%; MPN RC0402JR-074K7L
R29, R30, R39: 0R; R0402
R35: 510k; R0402
RST1: SW_Push; SW_Push_1P1T_NO_Vertical_Wuerth_434133025816
TP1, TP2, TP3: Test Point; TP-D35MIL; Part Type Test Point
U1: HX6538; WLCSP65_5.6x2.3x0.56mm
U2: CH343P; QFN-16-EP_3x3mm_P0.5mm_EP1x1mm
U3: WR0331-18FF4R; X2SON-4
U4, U6: SY80004DQD; DFN6-0.5-1.5X1.5X0.65MM; MPN SY80004DQD
U5: W25Q128JWSIQ; SOIC-8_5.23x5.23mm_P1.27mm
X1: 24MHz; 4P2016

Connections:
1V8: C13.1, C19.2, C20.1, C21.1, C28.1, C29.2, Q1.1 (G), Q2.1 (G), R5.1, R21.2, R22.2, R25.1, TP2.1 (T), U1.F3 (VDDIO_SIF1), U1.G3 (VDDA_RX), U1.H5 (VDDA_TX), U1.L2 (VDDIO_SIF2), U3.1 (OUT), U5.8 (VCC)
/0V9: C4.1, C7.1, L1.2, U1.L4 (DCDC_OUT)
BOOTOPT0: D3.1 (K), R11.1, U1.F4 (BOOT_OPT)
GND: C1.2, C2.2, C3.2, C4.2, C5.2, C6.2, C7.2, C8.1, C9.2, C10.2, C11.1, C13.2, C14.2, C15.1, C17.2, C18.2, C19.1, C20.2, C21.2, C22.2, C23.2, C24.1, C25.1, C26.2, C27.1, C28.2, C29.1, C30.1, C31.2, C34.2, C35.1, C37.1, C39.1, D5.1, D6.1, D7.1, D8.1, J1.A1_B1_A12_B12 (GND), J1.S1 (SHIELD), J2.1, J2.4, J2.7, J2.10, J2.MP (MountPin), J3.4, J3.MP (MountPin), J5.S1 (SHD1), J5.S2 (SHD2), J5.S3 (SHD3), J5.S4 (SHD4), J5.T6 (VSS), LED2.1 (K), M1.13 (GND), MIC1.4 (GND), MIC1.5 (L/R), MIC1.6 (GND), Q3.2 (S), R2.2, R3.2, R10.2, R11.2, R23.2, R26.1, R34.1, R37.2, RST1.2, TP3.1 (T), U1.C5 (GND1), U1.G4 (GND2), U1.H3 (GND3), U1.L3 (GND4), U1.M2 (GND5), U1.M4 (GND6), U2.2 (GND), U2.17 (EPAD), U3.2 (GND), U3.T (GND), U4.4 (GND), U5.4 (GND), U6.4 (GND), X1.2 (1), X1.4 (3)
GROVE_5V_IN: C18.1, C34.1, C35.2, J3.3, R14.1, R15.1, R31.2, R32.2, U6.6 (IN)
I2CS0_SCL/5V: J3.1, Q4.3 (D), R14.2
I2CS0_SDA/5V: J3.2, Q5.3 (D), R15.2
M_3V3_SCL: J2.13, Q1.3 (D), R19.2
M_3V3_SDA: J2.14, Q2.3 (D), R20.2
unnamed: BOOT1.2, R4.2
unnamed: D1.2 (A), R36.2
unnamed: C9.1, C10.1, C27.2, D2.1 (K), D4.1 (K), R6.2, R8.2, U4.6 (IN)
unnamed: BOOT1.1, D3.2 (A), R36.1
unnamed: J1.A5 (CC1), R2.1
unnamed: J1.B5 (CC2), R3.1
unnamed: LED1.2 (A), R38.1
unnamed: LED1.1 (K), Q3.3 (D)
unnamed: LED2.2 (A), R24.2
unnamed: M1.12 (3V3), R39.2
unnamed: MIC1.2 (CLK), R29.1
unnamed: MIC1.3 (DATA), R30.1
unnamed: Q3.1 (G), R37.1, R40.2
unnamed: R10.1, U1.E4 (TEST_MODE)
unnamed: L1.1, U1.L5 (VX1)
unnamed: C14.1, R35.1, U1.G2 (XTAL_24M_I), X1.3 (4)
unnamed: C15.2, R35.2, U1.F1 (XTAL_24M_O), X1.1 (2)
unnamed: C16.2, U2.13 (RTS)
unnamed: R8.1, U4.1 (EN)
unnamed: C32.1, R16.1, R26.2, U4.3 (FB)
unnamed: L2.1, U4.5 (LX)
unnamed: R6.1, U4.2 (PG)
unnamed: R31.1, U6.1 (EN)
unnamed: C36.1, R33.1, R34.2, U6.3 (FB)
unnamed: L3.1, U6.5 (LX)
unnamed: R32.1, U6.2 (PG)
PA0/3V3: M1.1 (D0/A0), U1.D4 (PA0)
PA1/VMUTE/3V3: J2.11, U1.C4 (PA1)
PA2/I2CS0_SCL/3V3: M1.6 (D5/SCL), Q4.2 (S), R1.1, R17.2, U1.A4 (PA2)
PA3/I2CS0_SDA/3V3: M1.5 (D4/SDA), Q5.2 (S), R13.1, R18.2, U1.B4 (PA3)
PB0/RX0/3V3: U1.A5 (PB0), U2.4 (TXD)
PB1/TX0/3V3: U1.B5 (PB1), U2.5 (RXD)
PB2/SSPIM_DO/3V3: D7.2, J5.T3 (CMD), M1.11 (D10/MOSI), R12.2, U1.N5 (PB2)
PB3/SSPIM_DI/3V3: D5.2, J5.T7 (DAT0), M1.10 (D9/MISO), R9.2, U1.M3 (PB3)
PB4/SSPIM_SCLK/3V3: D6.2, J5.T5 (CLOCK), M1.9 (D8/SCK), R27.2, U1.N4 (PB4)
PB5/SSPIM_~CS/3V3: D8.2, J5.T2 (CD/DAT3), R28.2, U1.N3 (PB5)
PB6/UART1_RX/3V3: M1.7 (D6/TX), U1.N1 (PB6)
PB7/UART1_TX/3V3: M1.8 (D7/RX/SS), U1.M1 (PB7)
PB8/3V3: M1.3 (D2/A2), U1.L1 (PB8)
PB9/PDM_CLK/3V3: R29.2, U1.F5 (PB9)
PB10/PDM_DATA0/3V3: R30.2, U1.G5 (PB10)
PB11/3V3: M1.2 (D1/A1), U1.J3 (PB11)
QSPI_CLK: U1.C2 (QSPI_CLK), U5.6 (CLK)
QSPI_CS: R5.2, U1.B2 (QSPI_CS), U5.1 (~CS)
QSPI_D0: U1.B1 (QSPI_DIO0), U5.5 (DI(IO0))
QSPI_D1: U1.D3 (QSPI_DIO1), U5.2 (DO(IO1))
QSPI_D2: U1.A1 (QSPI_DIO2), U5.3 (IO2)
QSPI_D3: U1.E3 (QSPI_DIO3), U5.7 (IO3)
RST: C3.1, C16.1, M1.4 (D3/A3), R7.1, RST1.1, U1.E5 (RESETN)
RX_CK_N: J2.8, U1.E2 (RX_CKN)
RX_CK_P: J2.9, U1.F2 (RX_CKP)
RX_D0_N: J2.2, U1.D2 (RX_DN0)
RX_D0_P: J2.3, U1.C1 (RX_DP0)
RX_D1_N: J2.5, U1.D1 (RX_DN1)
RX_D1_P: J2.6, U1.E1 (RX_DP1)
SEN_D1/SD~INSERT: J5.G1 (SWITCH), R25.2, U1.G1 (SEN_D1)
SEN_I2CM_SCL: Q1.2 (S), R21.1, U1.A3 (SEN_I2CM_SCL)
SEN_I2CM_SDA: Q2.2 (S), R22.1, U1.B3 (SEN_I2CM_SDA)
UD+: J1.A6 (D+), J1.B6 (D+), U2.7 (D+)
UD-: J1.A7 (D-), J1.B7 (D-), U2.8 (D-)
USER_LED/1V8: R40.1, U1.K2 (SEN_D2)
USR_BTN/1V8: D1.1 (K), R23.1, U1.H1 (SEN_D0)
V33IO: C2.1, C31.1, U2.1 (VIO), U2.6 (V3)
VBUS: C1.1, C30.2, D4.2 (A), J1.A4_B4_A9_B9 (VBUS), U2.3 (VDD5), U2.9 (VBUS)
VCC_3V3: C5.1, C6.1, C8.2, C11.2, C17.1, C22.1, C23.1, C24.2, C25.2, C26.1, C32.2, C36.2, C37.2, C39.2, J2.15, J5.T4 (VDD), L2.2, L3.2, MIC1.1 (VDD), Q4.1 (G), Q5.1 (G), R1.2, R4.1, R7.2, R9.1, R12.1, R13.2, R16.2, R17.1, R18.1, R19.1, R20.1, R24.1, R27.1, R28.1, R33.2, R38.2, R39.1, TP1.1 (T), U1.D5 (VDDIO_AON), U1.M5 (VDDA_DCDC), U1.N2 (VDDIO_PIF), U3.3 (EN), U3.4 (IN)
VMAIN: D2.2 (A), M1.14 (VUSB)

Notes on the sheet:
MIPI CSI
AON 3V3
MIPI DSI
PIF 3V3
SIF only 1V8
Imax=600mA
23/11/14
Grove - Vision AI Module V2
JN.FUONG



Board: 4 copper layers, 40.0 x 20.0 mm, 112 parts (31 on the bottom side), 75 nets.

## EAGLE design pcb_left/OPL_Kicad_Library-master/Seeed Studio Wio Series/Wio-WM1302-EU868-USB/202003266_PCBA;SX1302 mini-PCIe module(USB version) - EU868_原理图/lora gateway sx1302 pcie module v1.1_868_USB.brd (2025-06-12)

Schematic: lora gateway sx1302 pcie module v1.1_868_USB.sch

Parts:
ANT1: U.FL-R-SMT-1(10); U-FL3P-SMD-2.6X2.6X1.0MM
ANT2: DNP; U-FL3P-SMD-2.6X2.6X1.0MM
C1, C12, C15, C19, C23, C25, C26, C29, C32, C41, C43, C45, C65, C67, C80, C83, C86, C88: 100nF; C0402
C2, C75: 2.2pF; C0402
C3, C92: 10uF; C0603
C4, C8, C11, C16, C17, C18, C64: 56pF; C0402
C5, C6, C9, C10: 3.6pF; C0402
C7, C91: 5.6pF; C0402
C13, C20, C21, C24, C28, C35, C39, C40, C42, C44, C47, C48, C76, C87, C89: 1uF; C0402
C14, C38, C57, C66, C81, C84: 10pF; C0402
C22, C27, C33: 10uF; C0603@1
C30, C56, C74, C77, C78, C79: DNP; C0402
C31: DNP; C0603@1
C34, C46, C63: 470nF; C0402
C36: 47nF; C0402
C37: 47pF; C0402
C49: 4.7uF; C0603
C50, C62, C85: 10nF; C0402
C51: 1nF; C0402
C52, C55: 100pF; C0402
C53, C60, C61: 3.3pF; C0402
C54: 39pF; C0402
C58: 1.3pF; C0402
C59, C68, C73: 1.8pF; C0402
C69, C70, C71, C72: 10uF; C0805
C82: 2.7pF; C0402
C90: 2.2uF; C0603
D1, D4: Green; LED-0402
D2: Red; LED-0402
D3: Blue; LED-0402
D5: LXES15AAA1-153; ESD-0402
D6: DNP; ESD-0402
D7: BAT54XV2T1G; SOD-523
FB1: BLM15PD121SN1D; F0402
J1: DNP; PCIE52P-0.8-50.95X30MM
L1: LQP15MN1N2B02D; L0402
L2: LQW15AN6N8G00D; L0402
L4: 0R; F0603
L5: LQH44PN1R0NP0L; L4.4X3.0MM
L6, L14, L20: MLZ2012M150WT; L0805
L7, L15, L18, L21: DNP; L0402
L8: LQW15AN3N0B00; L0402
L9: LQW15AN47NJ00D; L0402
L10: LQW15AN2N5B00D; L0402
L11: LQW15AN4N7C00D; L0402
L12, L13: LQW15AN12NG00D; L0402
L16: LQW15AN7N5G00D; L0402
L17, L24: LQW15AN5N6C10D; L0402
L22: LQW15AN15NG00D; L0402
Q8: CJ2101; SOT-323
Q10: CJ2102; SOT-323
R1, R4, R33, R34, R38, R42, R57, R65, R71: 10k; R0402
R2, R7: 0R; R0603
R3, R8, R11, R12, R43, R44, R46, R49, R51, R55, R56, R59, R60, R61, R62, R63, R67, R70, R72, R73, R74, R75, R76, R81: DNP; R0402
R5, R10, R14, R15, R16, R39, R40, R41: 100R; R0402
R6, R9, R37: 220R; R0402
R13, R35, R52: DNP; R0603
R17, R18, R19, R20, R21, R22, R23, R24, R25, R26, R27, R28, R29, R36, R45, R48, R50, R53, R54, R69, R77: 0R; R0402
R30, R31, R32: 680R; R0402
R47, R79: 1k; R0402
R58, R68: 4.7k; R0402
R64, R66: 22R; R0402
R78, R82: 100k; R0402
R80: 10R; R0402
R83, R87: 200k_1%; R0402
S1, S2, S3, S4, S5, S6: 323030226; SHIELD_CLIP
TP1, TP2, TP3, TP4, TP5, TP6, TP7, TP8, TP9, TP10, TP14: TEST-POINT-35; TP_3535
TP15: TEST-POINT'4545'; TP-D45MIL
U1: SX1302IMLTRT; QFN68-0.35-7X7X0.75MM
U2, U8, U10: HDF866A3-S6; FILTER6P-1.1-3X3X1.3MM
U3, U4: DNP; SOT-23-5
U5, U7: SX1250IMLTRT; QFN24G-0.5-4X4MM
U6: MP2161GJ; TSOT23-8
U9: SKY66420-11; MODULE16P-0.5-3X3X0.75MM
U11: SX1262IMLTRT; QFN24G-0.5-4X4MM
U12: STM32L412K8U6; UFQFPN32-0.5-5X5MM
U13: STTS751; UDFN-6L
X1: DSB221SDN; X4-SMD-2.5X2.0X1.0MM
X3: 32.768kHz; X2-SMD-3.2X1.5X0.55MM

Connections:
32MHZ: R6.2, R9.2, R37.2, X1.3 (OUT)
1302_CS: R33.2, R43.1, U1.1 (HOST_CSN), U12.10 (PA4)
1302_RESET: C1.2, D7.-, R1.2, U1.7 (RESET), U12.8 (PA2)
1302_RESET_HOST: D7.+, R59.1
CONFIG_OK: R31.1, U1.66 (GPIO0)
DM: J1.36, R66.1
DP: J1.38, R64.1
FEM_CS: R14.2, R34.1, U1.10 (RADIO_CTRL0), U3.3 (CE)
FEM_PA_ON: R15.2, U1.16 (RADIO_CTRL4)
GND: ANT1.GND1, ANT1.GND2, ANT2.GND1, ANT2.GND2, C2.1, C3.1, C5.1, C7.1, C9.1, C12.1, C13.1, C15.1, C16.1, C17.1, C18.1, C19.1, C20.1, C21.1, C22.1, C23.1, C24.1, C25.1, C26.1, C27.1, C28.1, C29.1, C30.1, C31.1, C32.1, C33.1, C34.1, C35.1, C36.1, C37.1, C39.1, C40.1, C41.1, C42.1, C43.1, C44.1, C45.1, C46.1, C47.1, C48.1, C49.1, C50.1, C51.1, C52.1, C55.1, C56.1, C57.1, C58.1, C60.2, C61.2, C62.1, C63.2, C65.2, C67.2, C69.1, C70.1, C71.1, C72.1, C73.2, C74.2, C76.1, C77.2, C78.2, C80.1, C81.2, C82.2, C83.1, C84.2, C85.1, C86.1, C87.1, C88.1, C89.1, C90.1, C92.1, D1.-, D2.-, D3.-, D4.-, D5.1, D6.1, J1.4 (GND), J1.9 (GND), J1.15 (GND), J1.18 (GND), J1.21 (GND), J1.26 (GND), J1.27 (GND), J1.29 (GND), J1.34 (GND), J1.35 (GND), J1.37 (GND), J1.40 (GND), J1.43 (GND), J1.50 (GND), J1.S1 (GND), J1.S2 (GND), Q10.2 (S), R1.1, R4.1, R11.1, R12.1, R17.2, R53.1, R53.2, R54.1, R54.2, R55.1, R55.2, R57.2, R73.1, R74.1, R74.2, R87.1, S1.S1, S1.S2, S1.S3, S1.S4, S1.S5, S2.S1, S2.S2, S2.S3, S2.S4, S2.S5, S3.S1, S3.S2, S3.S3, S3.S4, S3.S5, S4.S1, S4.S2, S4.S3, S4.S4, S4.S5, S5.S1, S5.S2, S5.S3, S5.S4, S5.S5, S6.S1, S6.S2, S6.S3, S6.S4, S6.S5, TP3.T, U1.6 (GND), U1.9 (GND), U1.15 (GND), U1.24 (GND), U1.25 (GND), U1.39 (GND), U1.46 (GND), U1.55 (GND), U1.62 (GND), U1.69 (GND), U2.1 (GND), U2.3 (GND), U2.4 (GND), U2.6 (GND), U3.2 (VSS), U4.2 (VSS), U5.7 (GND), U5.20 (GND), U5.PAD, U6.4 (PGND), U6.6 (AGND), U7.7 (GND), U7.20 (GND), U7.PAD, U8.1 (GND), U8.3 (GND), U8.4 (GND), U8.6 (GND), U9.10 (GND), U9.12 (GND), U9.17 (EPAD), U10.1 (GND), U10.3 (GND), U10.4 (GND), U10.6 (GND), U11.2 (GND), U11.5 (GND), U11.8 (GND), U11.20 (GND), U11.PAD, U12.16 (VSS), U12.32 (VSS), U12.PAD, U13.4 (ADDR/!THERM), U13.5 (GND), X1.2 (GND)
HOST_CS0: J1.51, R43.2
HOST_CS1: J1.25, R51.2
HOST_IO1: J1.33, R61.2
HOST_IO2: J1.31, R63.2
HOST_IO3: J1.23
HOST_IO4: J1.8, R67.2
HOST_IO5: J1.10, R60.2
HOST_IO6: J1.12
HOST_MISO: R39.1, R44.2
HOST_MOSI: J1.49, R46.2
HOST_RST: J1.22, R59.2, R77.2
HOST_SCK: J1.45, R49.2
I2C_SCL: R68.2, R76.1, R81.1, U12.29 (PB6), U13.1 (SCL)
I2C_SDA: R58.2, R70.1, R75.1, U12.30 (PB7), U13.6 (SDA)
MCU_RESET: C85.2, R71.2, R77.1, TP5.T, U12.4 (NRST)
MISO: R44.1, R45.1, U1.2 (HOST_MISO), U11.16 (MISO)
MISO_A: U1.42 (RADIO_A_MISO), U5.16 (MISO)
MISO_B: U1.33 (RADIO_B_MISO), U7.16 (MISO)
MOSI: R5.2, R40.2, R46.1, R48.1
MOSI_A: U1.67 (RADIO_A_MOSI), U5.17 (MOSI)
MOSI_B: U1.19 (RADIO_B_MOSI), U7.17 (MOSI)
unnamed: C11.2, U9.2 (RX)
unnamed: TP15.T, U6.1 (PG)
unnamed: C8.1, R11.2, R52.2, U8.5 (OUT)
unnamed: C2.2, L11.2, R52.1, U8.2 (IN)
unnamed: C11.1, R13.2, U2.2 (IN)
unnamed: C4.2, U9.1 (TX)
unnamed: C68.1, C74.1, C75.2
unnamed: C65.1, L18.2, R36.2, U11.1 (VDD_IN)
unnamed: C66.2, R37.1
unnamed: L5.1, U6.3 (SW)
unnamed: R83.1, R87.2, U6.7 (FB)
unnamed: R3.1, R4.2, X1.1 (ENABLE)
unnamed: C14.1, U5.3 (XTA)
unnamed: C62.2, L4.1, R3.2, X1.4 (VDD)
unnamed: R5.1, U1.3 (HOST_MOSI)
unnamed: D4.+, R47.2
unnamed: R10.1, U1.4 (HOST_SCK)
unnamed: R82.2, U6.8 (EN)
unnamed: R8.1, U4.3 (CE)
unnamed: C14.2, R6.1
unnamed: L6.2, U5.8 (DCC_SW)
unnamed: C34.2, L6.1, L7.2, U5.6 (VREG)
unnamed: C64.1, C82.1, L24.2
unnamed: R19.1, U1.34 (RADIO_B_CLK_I)
unnamed: C16.2, R14.1, U9.4 (CSD)
unnamed: C38.1, U7.3 (XTA)
unnamed: C36.2, C37.2, L9.2, U5.1 (VR_PA)
unnamed: C38.2, R9.1
unnamed: L14.2, U7.8 (DCC_SW)
unnamed: C46.2, L14.1, L15.2, U7.6 (VREG)
unnamed: C54.2, L11.1
unnamed: C7.2, C53.2, C54.1, L10.2
unnamed: C4.1, C8.2, R12.2
unnamed: C17.2, R15.1, U9.5 (CPS)
unnamed: C18.2, R16.1, U9.6 (CTX)
unnamed: R17.1, U1.20 (SP_VALID)
unnamed: R18.1, U1.32 (RADIO_B_IQ3)
unnamed: R20.1, U1.35 (RADIO_B_IQ0)
unnamed: R24.1, U1.41 (RADIO_A_IQ3)
unnamed: R21.1, U1.36 (RADIO_B_IQ1)
unnamed: R22.1, U1.37 (RADIO_B_IQ4)
unnamed: R23.1, U1.38 (RADIO_B_IQ2)
unnamed: R25.1, U1.43 (RADIO_A_CLK_I)
unnamed: R26.1, U1.44 (RADIO_A_IQ0)
unnamed: R27.1, U1.45 (RADIO_A_IQ1)
unnamed: R28.1, U1.48 (RADIO_A_IQ4)
unnamed: R29.1, U1.49 (RADIO_A_IQ2)
unnamed: D3.+, R32.2
unnamed: D2.+, R31.2
unnamed: D1.+, R30.2
unnamed: Q8.1 (G), Q10.3 (D), R78.2
unnamed: C1.1, R80.1
unnamed: L1.1, U9.16 (VCC1)
unnamed: L2.1, L8.1, U9.13 (PA_OUT)
unnamed: C56.2, C57.2, L8.2, L16.1
unnamed: C58.2, L16.2, U9.11 (TX_IN)
unnamed: C59.2, C60.1, L17.1, U9.9 (ANT)
unnamed: C61.1, C91.1, L17.2, L24.1
unnamed: C66.1, U11.3 (XTA)
unnamed: ANT1.D, C64.2, D5.2
unnamed: R35.2, R62.1, R69.2, U10.2 (IN)
unnamed: C63.1, L18.1, L20.1, U11.7 (VREG)
unnamed: R35.1, U9.7 (LNA_IN), U10.5 (OUT)
unnamed: L20.2, U11.9 (DCC_SW)
unnamed: J1.47, R39.2
unnamed: R40.1, U11.17 (MOSI)
unnamed: R41.1, U11.18 (SCK)
unnamed: C6.1, C10.1, C75.1, R13.1, U2.5 (OUT)
unnamed: R69.1, U9.8 (RX_FLT)
unnamed: C78.1, C79.1, L21.2
unnamed: ANT2.D, C79.2, D6.2
unnamed: C59.1, C91.2
unnamed: C77.1, L21.1, R62.2
unnamed: R65.2, U13.2 (!EVENT)
unnamed: C52.2, FB1.1, L1.2, U9.15 (VCC0)
unnamed: R64.2, U12.22 (PA12)
unnamed: R66.2, U12.21 (PA11)
unnamed: C92.2, Q10.1 (G), R79.2
unnamed: R56.2, R57.1, U12.31 (BOOT0)
unnamed: R72.2, R73.2, U12.6 (PA0-CLK_IN)
unnamed: C81.1, U12.2 (PC14-OSC32_IN), X3.2
unnamed: C84.1, U12.3 (PC15-OSC32_OUT), X3.1
unnamed: J1.14, R76.2
unnamed: J1.16, R70.2
unnamed: J1.30, R81.2
unnamed: J1.32, R75.2
PPS: J1.19, TP2.T, U1.8 (PPS), U12.27 (PB4)
RADIO_A_CLK_32M: R25.2, R72.1, U5.14 (BUSY)
RADIO_A_CLK_O: R28.2, U5.11 (DIO5)
RADIO_A_CSN: U1.68 (RADIO_A_CSN), U5.19 (NSS)
RADIO_A_IQ_0: R26.2, U5.13 (DIO1)
RADIO_A_IQ_1: R27.2, U5.12 (DIO2)
RADIO_A_IQ_2: R29.2, U5.5 (DIO3)
RADIO_A_IQ_3: R24.2, U5.21 (DIO4)
RADIO_A_RESET: U1.13 (RADIO_CTRL3), U5.15 (NRESET)
RADIO_A_RFIN: C6.2, L12.2, U5.23 (RFI_N)
RADIO_A_RFIP: C5.2, L12.1, U5.22 (RFI_P)
RADIO_B_CLK_32M: R19.2, U7.14 (BUSY)
RADIO_B_CLK_O: R22.2, U7.11 (DIO5)
RADIO_B_CSN: U1.18 (RADIO_B_CSN), U7.19 (NSS)
RADIO_B_IQ0: R20.2, U7.13 (DIO1)
RADIO_B_IQ_1: R21.2, U7.12 (DIO2)
RADIO_B_IQ_2: R23.2, U7.5 (DIO3)
RADIO_B_IQ_3: R18.2, U7.21 (DIO4)
RADIO_B_RESET: U1.28 (RADIO_CTRL9), U7.15 (NRESET)
RADIO_B_RFIN: C10.2, L13.2, U7.23 (RFI_N)
RADIO_B_RFIP: C9.2, L13.1, U7.22 (RFI_P)
RFO: C53.1, L9.1, L10.1, U5.24 (RFO)
RX_ON: R32.1, U1.59 (GPIO4)
SCK: R10.2, R41.2, R49.1, R50.1
SCK_A: U1.65 (RADIO_A_SCK), U5.18 (SCK)
SCK_B: U1.21 (RADIO_B_SCK), U7.18 (SCK)
STM32_MISO: R45.2, U12.12 (PA6)
STM32_MOSI: R48.2, U12.13 (PA7)
STM32_SCK: R50.2, U12.11 (PA5)
SWCLK: TP7.T, U12.24 (PA14)
SWDIO: TP8.T, U12.23 (PA13)
SX1261_BUSY: R67.1, U11.14 (BUSY), U12.9 (PA3)
SX1261_CS: R42.1, R51.1, U11.19 (NSS), U12.14 (PB0)
SX1261_IO1: R61.1, U1.54 (GPIO7), U11.13 (DIO1), U12.15 (PB1)
SX1261_IO2: R63.1, U11.12 (DIO2)
SX1261_IO3: TP9.T, U11.6 (DIO3)
SX1261_RFIN: C68.2, L22.2, U11.22 (RFI_N)
SX1261_RFIP: C73.1, L22.1, U11.21 (RFI_P)
SX1261_RST: R38.1, R60.1, U11.15 (NRESET), U12.18 (PA8)
SX1302_GPIO8: U1.53 (GPIO8), U12.26 (PB3)
TX_ON: R30.1, U1.63 (GPIO2)
TX_RX_SW: R16.2, U1.12 (RADIO_CTRL2)
VCCIO: C3.2, C19.2, C20.2, C25.2, C28.2, C41.2, C42.2, C45.2, C47.2, C76.2, C80.2, C83.2, C86.2, C87.2, C88.2, C89.2, C90.2, Q8.3 (D), R33.1, R34.2, R56.1, R58.1, R65.1, R68.1, R71.1, R80.2, TP1.T, U1.14 (VCC_IO), U1.30 (VCC_IO), U1.47 (VCC_IO), U1.61 (VCC_IO), U12.1 (VDD), U12.5 (VDDA), U12.17 (VDD), U13.3 (VDD)
VCC_1V2: C12.2, C13.2, C23.2, C24.2, C29.2, C40.2, C43.2, C44.2, C71.2, C72.2, L5.2, R79.1, R83.2, TP14.T, U1.5 (VCC_CORE), U1.23 (VCC_CORE), U1.40 (VCC_CORE), U1.56 (VCC_CORE), U6.5 (OUT)
VCC_FEM: C26.2, C27.2, C49.2, C50.2, C51.2, C55.2, FB1.2, L2.2, R2.2, TP6.T, U3.5 (VOUT)
VCC_RADIO: C21.2, C32.2, C33.2, C35.2, C39.2, C48.2, C67.1, L4.2, L7.1, L15.1, R7.2, R36.1, R38.2, R42.2, TP10.T, U4.5 (VOUT), U5.2 (VDD_IN), U5.9 (VBAT_RF), U5.10 (VBAT_DIO), U7.2 (VDD_IN), U7.9 (VBAT_RF), U7.10 (VBAT_DIO), U11.10 (VBAT), U11.11 (VBAT_IO)
VIN: C15.2, C22.2, C30.2, C31.2, C69.2, C70.2, J1.2 (3V3), J1.24 (3V3), J1.39 (3V3), J1.41 (3V3), J1.52 (3V3), Q8.2 (S), R2.1, R7.1, R8.2, R47.1, R78.1, R82.1, TP4.T, U3.1 (VIN), U4.1 (VIN), U6.2 (VIN)

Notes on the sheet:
V1.0
Initial Release
2020/01/02
Vincent
50ohm Impedence
3.3V
300mA
1.2V
500mA
100mA
USB
868
915
SPI
For Power-up delay
V1.1
Add power up delay circuit at VCCIO
Add power up reset circuit for SX1302
Change pins refer to Semtech V3 Schematic
2021/02/18



Board: 4 copper layers, 30.0 x 51.0 mm, 244 parts (68 on the bottom side), 162 nets.

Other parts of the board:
U$45: SEEED-SILK-TNAME-280*268MIL

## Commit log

2025-06-12 Added PCB and the BOM
    [Grove - Vision AI Module V2.kicad_pcb, Grove - Vision AI Module V2.kicad_sch, Grove_Vision_AI_V2_BOM.xlsx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]
2025-06-12 Added PCB images and BOM
2025-06-13 Updated PCB
    [hexboard-Edge_Cuts-right.dxf, hexboard-Edge_Cuts.dxf, hexboard-User_Drawings.dxf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]
2025-06-17 updated folder structure, remove screw holes
    [Grove - Vision AI Module V2.kicad_pcb, Grove - Vision AI Module V2.kicad_sch, Grove_Vision_AI_V2_BOM.xlsx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]
2025-06-18 Added STEP files for the case, both halves
    [Bottom Shell Left.step, Bottom Shell Right.step, Top Plate Left.step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]
2025-06-19 Created a production folder
    [Bottom Shell Left.step, Bottom Shell Right.step, Top Plate Left.step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]
2025-06-19 Committing any uncommitted changes
    [hexboard.kicad_pcb]
2025-06-20 Update README.md to reflect case and keycap cost
2025-06-24 added design to case, colorized 3mf files
    [Bottom Shell Left.step, Bottom Shell Right.step, Left Plate.3mf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]
2025-06-25 update pcb if necessary
    [Left Cover.step, Right Cover.step]
